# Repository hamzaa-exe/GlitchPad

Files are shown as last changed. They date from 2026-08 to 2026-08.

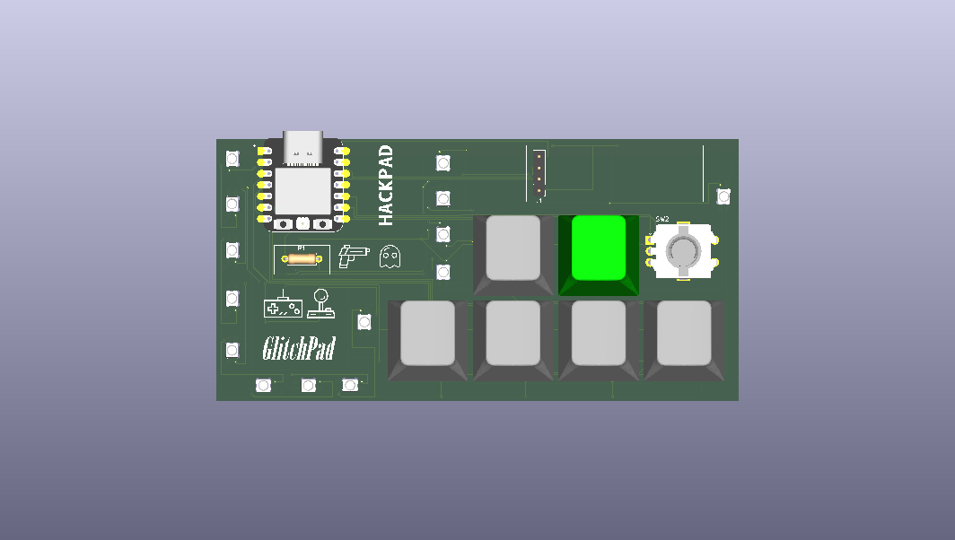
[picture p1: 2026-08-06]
PCB/GlitchPad.png

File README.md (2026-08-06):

# GlitchPad 

### A compact gaming macropad built for fast inputs, RGB glow, and cyberpunk vibes.

---

##  Renders

case final 1
GlitchPad
PCB FINALLLLLLLLL
schematic complete

##  What is GlitchPad?

**GlitchPad** is a custom gaming macropad built around the **Seeed XIAO RP2040**, **KMK firmware**, a rotary encoder, OLED display, and **20 SK6812 Mini-E RGB LEDs**.

It's designed mainly for FPS gaming, while still being fully customizable for other uses.

### Features

*  6 Cherry MX-compatible switches
*  EC11 rotary encoder
*  0.91" OLED display
*  20 × SK6812 Mini-E LEDs
*  XIAO RP2040
*  Custom 3D-printed case
*  Custom PCB
*  KMK firmware
*  Cyber-blue glitch lighting

---

##  Button Layout

```text
             SPACE       UP

             SHIFT      LEFT      DOWN      RIGHT
```

The rotary encoder is designed for quick number-based controls, such as switching between weapon slots in FPS games.

---

##  OLED + RGB

The OLED features a custom glitch-style animation, while the 20 SK6812 Mini-E LEDs provide a **cyber-blue pulse** aesthetic.

---

##  BOM

See the complete Bill of Materials here:

**[View BOM](./BOM.md)**

---

##  Tools

* **KiCad** — PCB & schematic
* **Fusion 360** — CAD & case
* **KMK + CircuitPython** — Firmware

---

##  Why GlitchPad?

I wanted to build a compact gaming controller while learning more about **PCB design, CAD, firmware, and hardware manufacturing**.

Six buttons. One encoder. Twenty LEDs.

**That's GlitchPad. **

---

##  Author

**Hamza Sohail**

Built for **Hack Club Hackpad**.

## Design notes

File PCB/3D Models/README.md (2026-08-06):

This folder include all 3D models used in PCB designimg

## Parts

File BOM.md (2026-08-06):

## Bill of Materials (BOM)

| **Component** | **Specification** | **Quantity** |
|---|---|---:|
| **Microcontroller** | Seeed XIAO RP2040 | 1 |
| **Mechanical switches**| Cherry MX-compatible switches | 6 |
| **Keycaps** | Cherry MX-compatible | 6 |
| **Rotary encoder** | EC11 rotary encoder | 1 |
| **OLED display** | 0.91" I²C OLED, 128×32 | 1 |
| **RGB LEDs** | SK6812 Mini-E | 20 |
| **Resistor** | 330 Ω | 1 |
| **PCB** | Custom GlitchPad PCB | 1 |
| **Case** | Custom 3D-printed case | 1 |
| **Screws** | M3 × 16 mm | 4 |
| **USB cable** | Compatible with XIAO RP2040 | 1 |

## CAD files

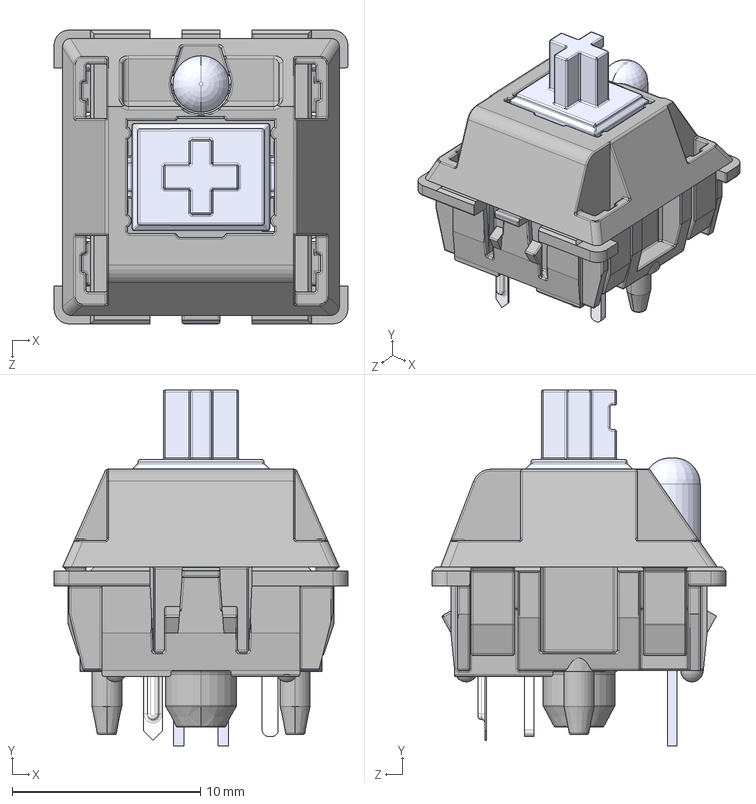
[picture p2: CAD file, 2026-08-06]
PCB/3D Models/MX .STEP
15.6 x 18.9 x 15.6 mm
MX 轴 按键′_ü___¨1
MX 轴 轴体áì_¨￠¨__
MX粣 拸簽LEDLEDLED
MX轴 轴体 底部 μ×2__默认_á2____è_
针脚___默认__è_

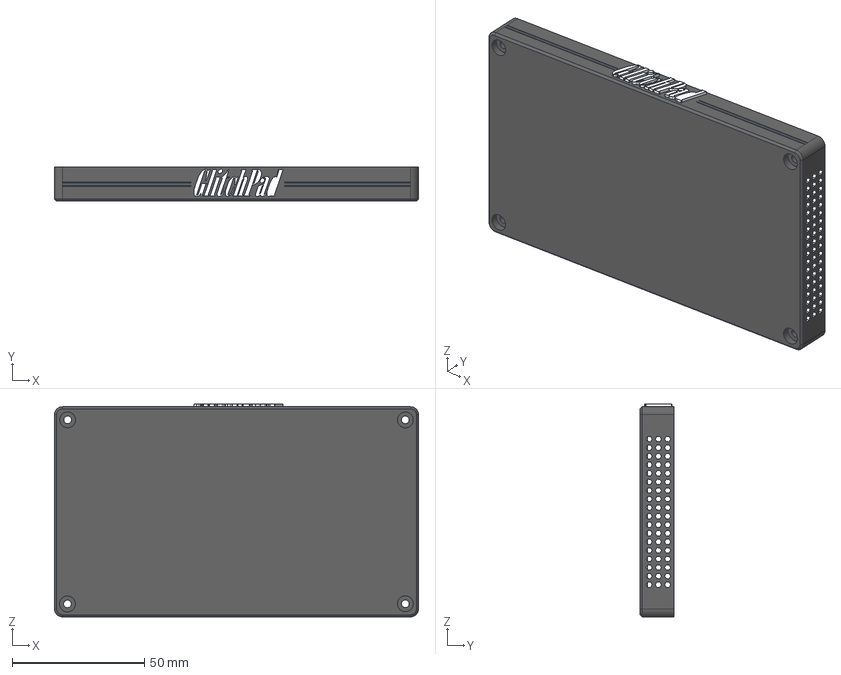
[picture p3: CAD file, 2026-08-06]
production/GlitchPad Case.step
137.5 x 13.0 x 80.4 mm

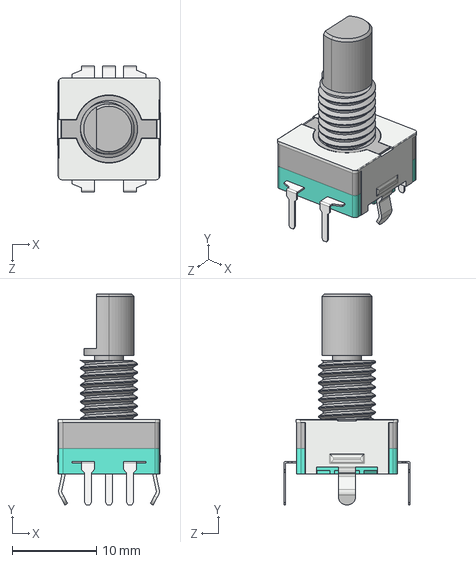
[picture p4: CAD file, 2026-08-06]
PCB/3D Models/旋转编码器.STEP
12.3 x 25.1 x 15.0 mm

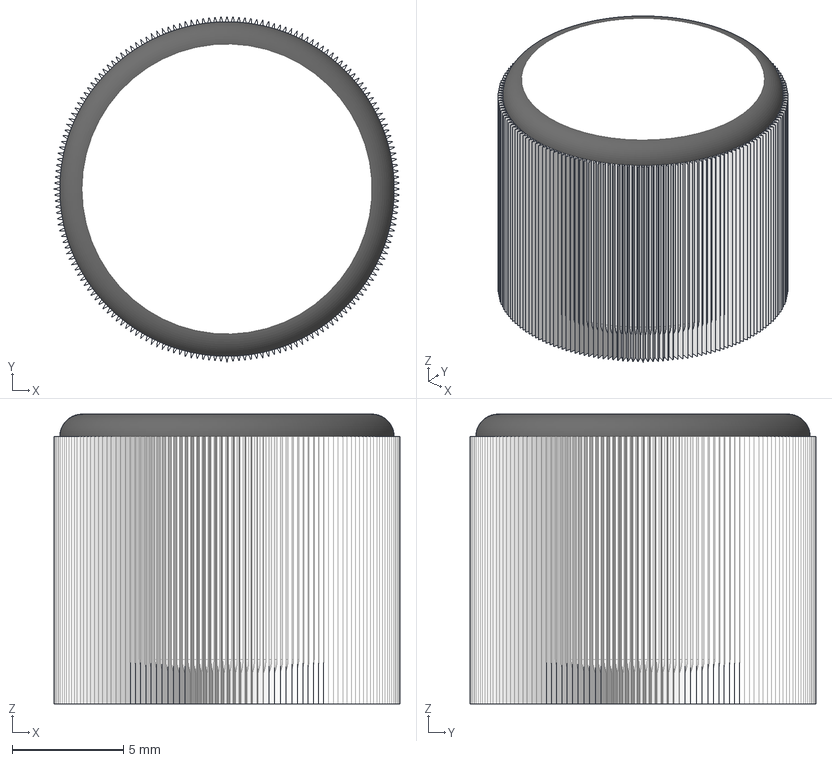
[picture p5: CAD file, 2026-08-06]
production/GlitchPad knob.step
15.5 x 15.5 x 13.0 mm

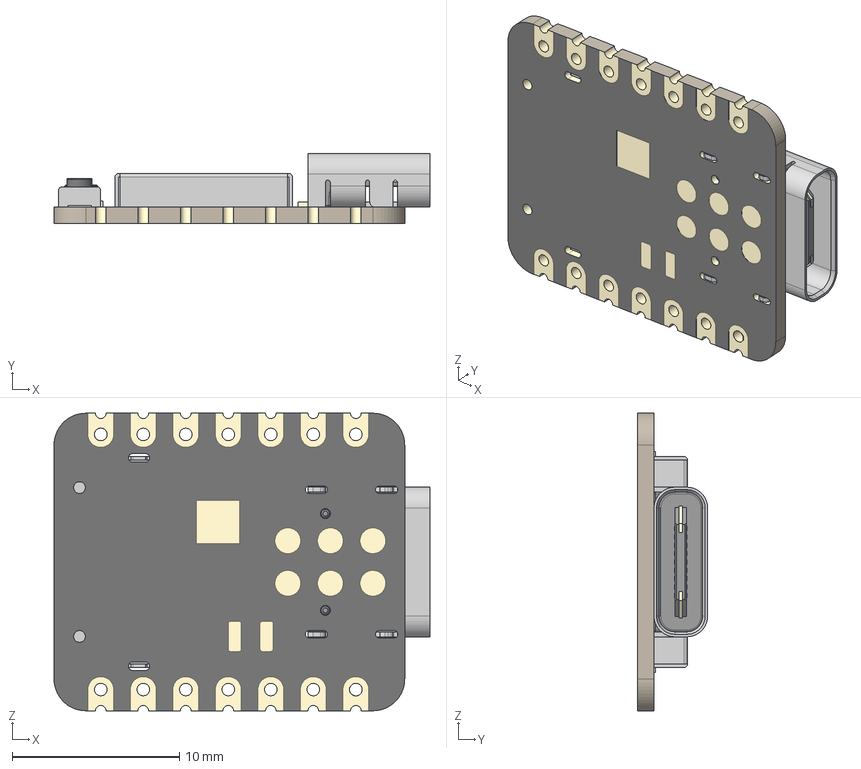
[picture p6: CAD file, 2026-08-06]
PCB/3D Models/Seeed Studio XIAO-ESP32-C3.step
22.5 x 4.21 x 17.8 mm
BOSS-EXTRUDE14_8_
BOSS-EXTRUDE7_4_
BOSS-EXTRUDE7_3_
BOSS-EXTRUDE14_4_
BOSS-EXTRUDE14_2_
BOSS-EXTRUDE14_11_
BOSS-EXTRUDE7_7_
BOSS-EXTRUDE14_9_
BOSS-EXTRUDE14_3_
BOSS-EXTRUDE14_7_
MIRROR2
BOSS-EXTRUDE14_5_
BOSS-EXTRUDE14_12_
BOSS-EXTRUDE7_8_
BOSS-EXTRUDE7_1_
BOSS-EXTRUDE14_10_
BOSS-EXTRUDE7_9_
BOSS-EXTRUDE14_6_
BOSS-EXTRUDE14_1_
BOSS-EXTRUDE7_6_
BOSS-EXTRUDE7_2_
CUT-EXTRUDE5
BOSS-EXTRUDE7_5_
U.FL Connector v1
Button (1) x 2
Shield

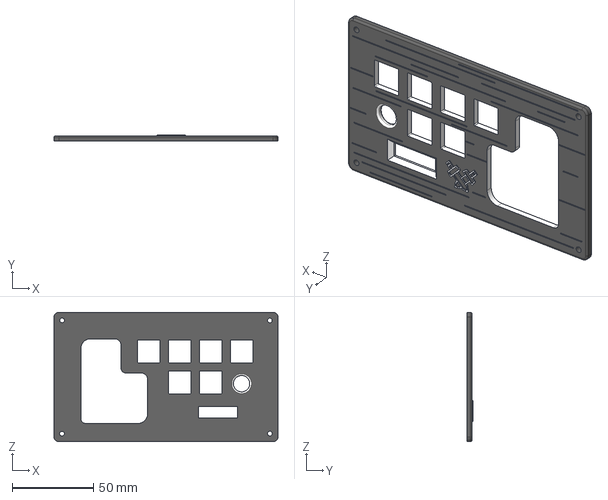
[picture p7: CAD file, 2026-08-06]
production/GlitchPad Case (Upper).step
137.5 x 3.50 x 79.4 mm

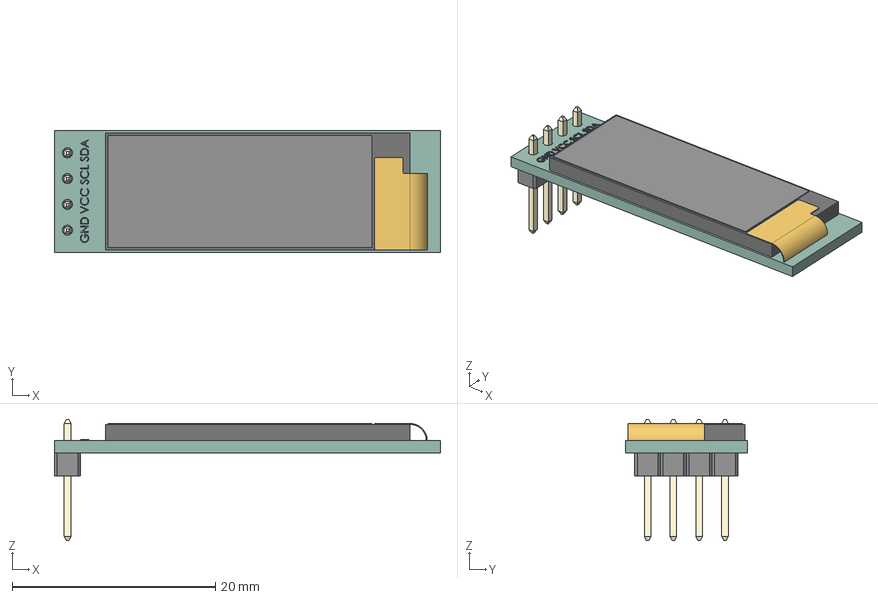
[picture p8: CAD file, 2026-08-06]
PCB/3D Models/128x32-OLED.STEP
38.0 x 12.0 x 11.9 mm

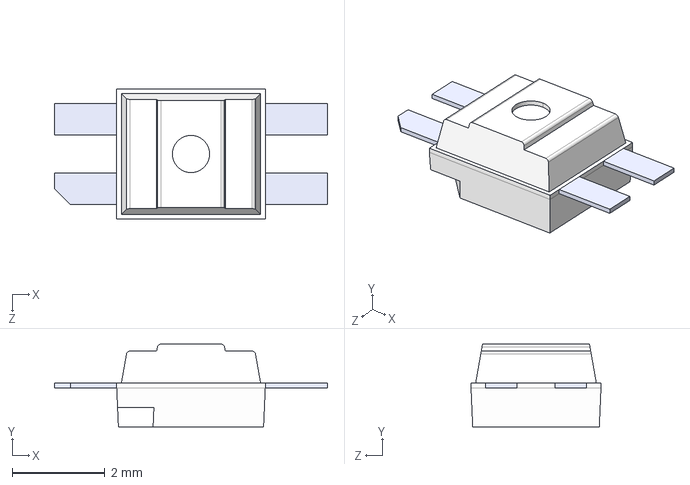
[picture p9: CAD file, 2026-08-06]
PCB/3D Models/SK6812MINI-E--3DModel-STEP-418109.STEP
5.88 x 1.78 x 2.80 mm

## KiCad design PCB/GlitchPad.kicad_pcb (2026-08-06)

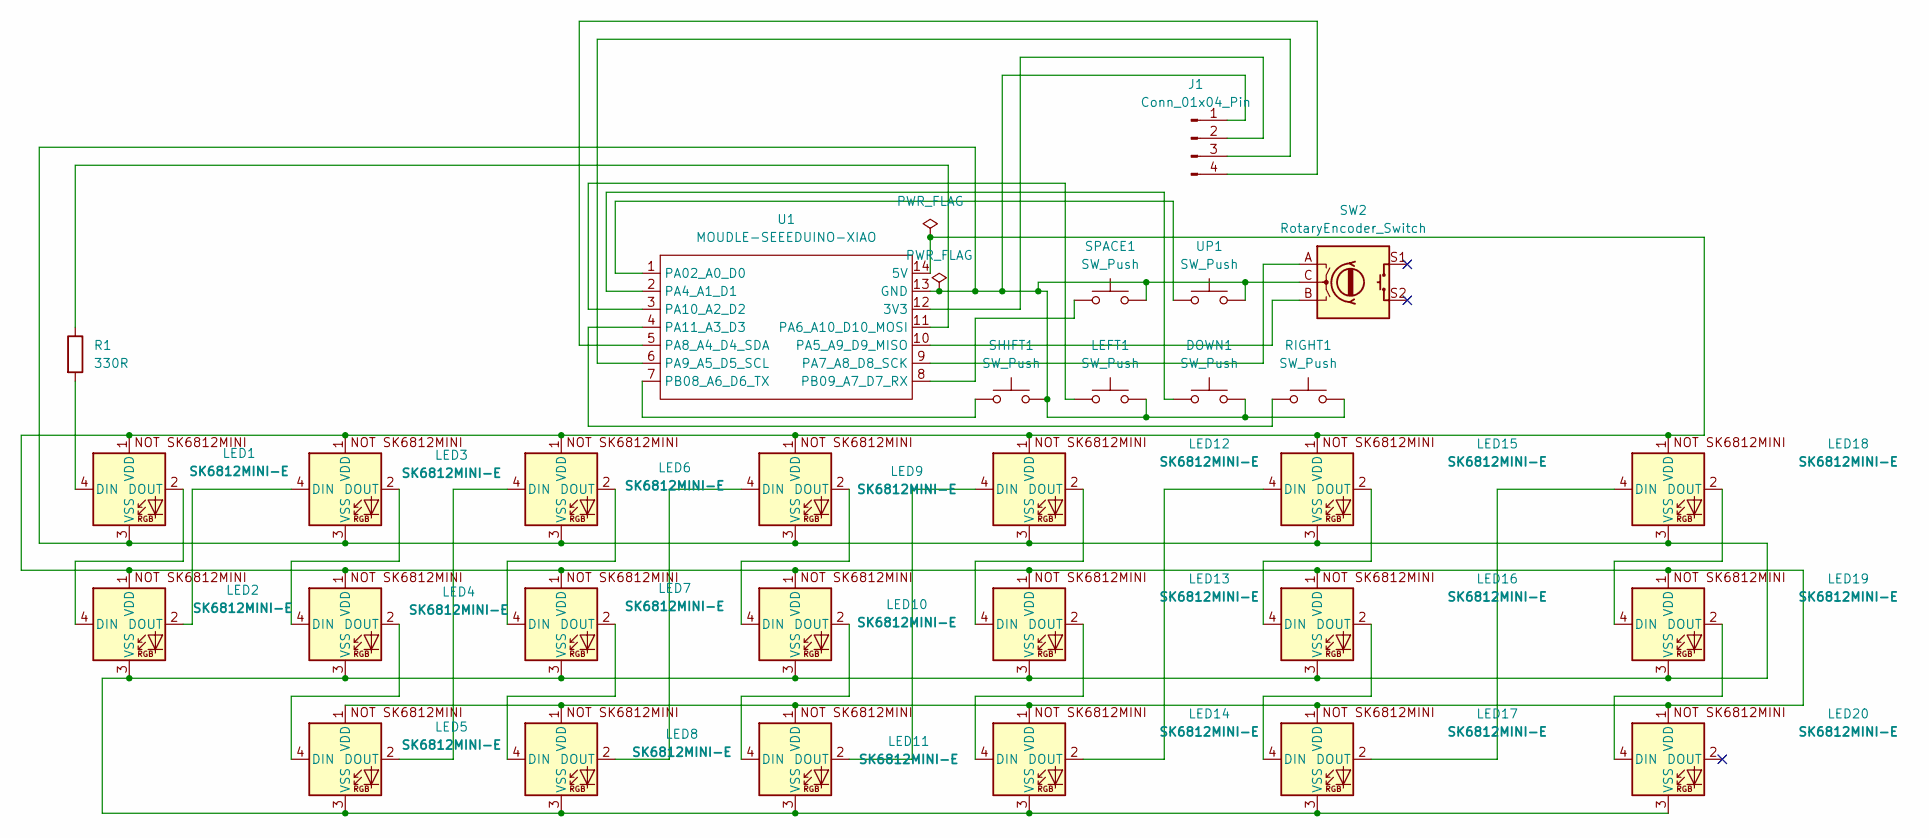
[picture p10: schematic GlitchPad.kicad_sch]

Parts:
DOWN1: SW_Push; SW_Cherry_MX_1.00u_PCB
J1: Conn_01x04_Pin; PinHeader_1x04_P2.54mm_Vertical
LED1, LED2, LED3, LED4, LED5, LED6, LED7, LED8, LED9, LED10, LED11, LED12, LED13, LED14, LED15, LED16, LED17, LED18, LED19, LED20: SK6812MINI-E; SK6812MINI-E_fixed
LEFT1: SW_Push; SW_Cherry_MX_1.00u_PCB
R1: 330R; R_Axial_DIN0207_L6.3mm_D2.5mm_P7.62mm_Horizontal
RIGHT1: SW_Push; SW_Cherry_MX_1.00u_PCB
SHIFT1: SW_Push; SW_Cherry_MX_1.00u_PCB
SPACE1: SW_Push; SW_Cherry_MX_1.00u_PCB
SW2: RotaryEncoder_Switch; RotaryEncoder_Alps_EC11E-Switch_Vertical_H20mm
U1: MOUDLE-SEEEDUINO-XIAO; XIAO-Generic-Hybrid-14P-2.54-21X17.8MM
UP1: SW_Push; SW_Cherry_MX_1.00u_PCB

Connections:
unnamed: DOWN1.2, J1.1, LED1.3 (VSS), LED2.3 (VSS), LED3.3 (VSS), LED4.3 (VSS), LED5.3 (VSS), LED6.3 (VSS), LED7.3 (VSS), LED8.3 (VSS), LED9.3 (VSS), LED10.3 (VSS), LED11.3 (VSS), LED12.3 (VSS), LED13.3 (VSS), LED14.3 (VSS), LED15.3 (VSS), LED16.3 (VSS), LED17.3 (VSS), LED18.3 (VSS), LED19.3 (VSS), LED20.3 (VSS), LEFT1.2, RIGHT1.2, SHIFT1.2, SPACE1.2, SW2.C, U1.13 (GND), UP1.2
unnamed: J1.2, U1.12 (3V3)
unnamed: J1.3, U1.6 (PA9_A5_D5_SCL)
unnamed: J1.4, U1.5 (PA8_A4_D4_SDA)
unnamed: LED1.4 (DIN), R1.2
unnamed: LED1.2 (DOUT), LED2.4 (DIN)
unnamed: LED1.1 (VDD), LED2.1 (VDD), LED3.1 (VDD), LED4.1 (VDD), LED5.1 (VDD), LED6.1 (VDD), LED7.1 (VDD), LED8.1 (VDD), LED9.1 (VDD), LED10.1 (VDD), LED11.1 (VDD), LED12.1 (VDD), LED13.1 (VDD), LED14.1 (VDD), LED15.1 (VDD), LED16.1 (VDD), LED17.1 (VDD), LED18.1 (VDD), LED19.1 (VDD), LED20.1 (VDD), U1.14 (5V)
unnamed: LED2.2 (DOUT), LED3.4 (DIN)
unnamed: LED3.2 (DOUT), LED4.4 (DIN)
unnamed: LED4.2 (DOUT), LED5.4 (DIN)
unnamed: LED5.2 (DOUT), LED6.4 (DIN)
unnamed: LED6.2 (DOUT), LED7.4 (DIN)
unnamed: LED7.2 (DOUT), LED8.4 (DIN)
unnamed: LED8.2 (DOUT), LED9.4 (DIN)
unnamed: LED9.2 (DOUT), LED10.4 (DIN)
unnamed: LED10.2 (DOUT), LED11.4 (DIN)
unnamed: LED11.2 (DOUT), LED12.4 (DIN)
unnamed: LED12.2 (DOUT), LED13.4 (DIN)
unnamed: LED13.2 (DOUT), LED14.4 (DIN)
unnamed: LED14.2 (DOUT), LED15.4 (DIN)
unnamed: LED15.2 (DOUT), LED16.4 (DIN)
unnamed: LED16.2 (DOUT), LED17.4 (DIN)
unnamed: LED17.2 (DOUT), LED18.4 (DIN)
unnamed: LED18.2 (DOUT), LED19.4 (DIN)
unnamed: LED19.2 (DOUT), LED20.4 (DIN)
unnamed: U1.1 (PA02_A0_D0), UP1.1
unnamed: DOWN1.1, U1.2 (PA4_A1_D1)
unnamed: SW2.B, U1.10 (PA5_A9_D9_MISO)
unnamed: R1.1, U1.11 (PA6_A10_D10_MOSI)
unnamed: SW2.A, U1.9 (PA7_A8_D8_SCK)
unnamed: LEFT1.1, U1.3 (PA10_A2_D2)
unnamed: RIGHT1.1, U1.4 (PA11_A3_D3)
unnamed: SHIFT1.1, U1.7 (PB08_A6_D6_TX)
unnamed: SPACE1.1, U1.8 (PB09_A7_D7_RX)

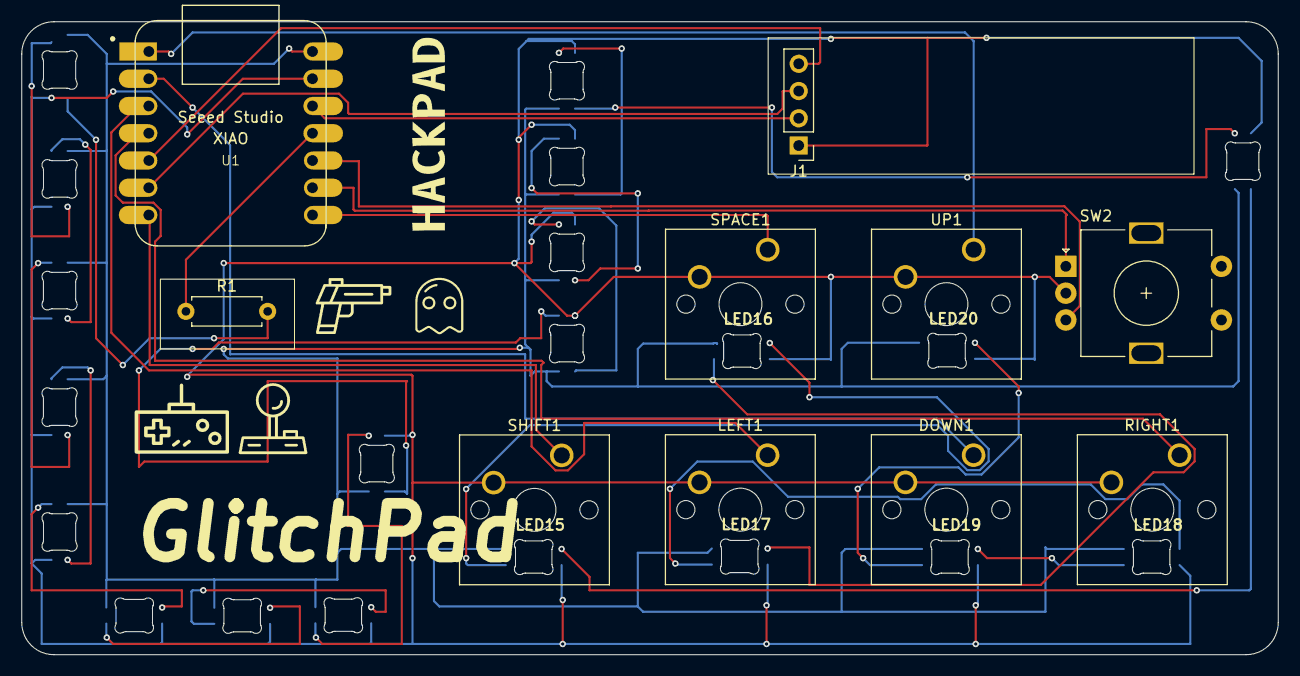
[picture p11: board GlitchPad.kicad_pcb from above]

Board: 2 copper layers, 117.1 x 59.0 mm, 30 parts (0 on the bottom side), 34 nets.

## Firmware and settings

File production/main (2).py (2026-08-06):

import time
import math
import board
import busio
import neopixel

from kmk.kmk_keyboard import KMKKeyboard
from kmk.keys import KC
from kmk.scanners.keypad import KeysScanner
from kmk.modules.encoder import EncoderHandler


# ============================================================
# GLITCHPAD
# ============================================================

keyboard = KMKKeyboard()


# ============================================================
# BUTTONS — DIRECT GPIO
#
# Each switch:
# GPIO ---- SWITCH ---- GND
#
# D0 = UP
# D1 = DOWN
# D2 = LEFT
# D3 = RIGHT
# D6 = SHIFT
# D7 = SPACE
# ============================================================

BUTTON_PINS = [
board.D0, # UP
board.D1, # DOWN
board.D2, # LEFT
board.D3, # RIGHT
board.D6, # SHIFT
board.D7, # SPACE
]

keyboard.matrix = KeysScanner(
pins=BUTTON_PINS,
value_when_pressed=False,
pull=True,
)

keyboard.keymap = [
[
KC.UP,
KC.DOWN,
KC.LEFT,
KC.RIGHT,
KC.LSFT,
KC.SPC,
]
]


# ============================================================
# ROTARY ENCODER
#
# D8 = A
# D9 = B
# C = GND
#
# Rotation selects number slots 1-9.
# ============================================================

encoder_handler = EncoderHandler()

encoder_handler.pins = (
(board.D8, board.D9, None, True),
)

encoder_handler.map = [
(
(KC.N1, KC.N2),
),
]

keyboard.modules.append(encoder_handler)


# ============================================================
# OLED
#
# D4 = SDA
# D5 = SCL
#
# 128 x 32 I2C OLED
# ============================================================

import adafruit_ssd1306

i2c = busio.I2C(
board.D5,
board.D4,
)

oled = adafruit_ssd1306.SSD1306_I2C(
128,
32,
i2c,
addr=0x3C,
)


# ============================================================
# SK6812 MINI-E
#
# D10 = LED1 DIN
# 20 LEDs total
# ============================================================

LED_COUNT = 20

pixels = neopixel.NeoPixel(
board.D10,
LED_COUNT,
brightness=0.15,
auto_write=False,
)


# ============================================================
# RGB — CYBER BLUE PULSE
# ============================================================

def update_rgb():
t = time.monotonic()

pulse = int(
20 + (math.sin(t * 4) + 1) * 25
)

for i in range(LED_COUNT):
variation = (i * 3) % 12

pixels[i] = (
0,
min(80, pulse // 3 + variation),
min(120, pulse + variation),
)

pixels.show()


# ============================================================
# OLED GLITCH DISPLAY
# ============================================================

glitch_text = [
"GLITCHPAD",
"GL1TCHPAD",
"GL!TCHPAD",
"GLITCHP4D",
]

frame = 0
last_oled_update = 0


def update_oled():
global frame
global last_oled_update

now = time.monotonic()

if now - last_oled_update < 0.18:
return

last_oled_update = now

oled.fill(0)

# Title
oled.text(
glitch_text[frame],
10,
0,
1,
)

# Status
oled.text(
"SYSTEM ONLINE",
5,
12,
1,
)

# Animated glitch bar
bar_length = (frame * 18) % 120

oled.fill_rect(
4,
23,
bar_length,
2,
1,
)

oled.text(
"READY",
48,
26,
1,
)

oled.show()

frame = (frame + 1) % len(glitch_text)


# ============================================================
# STARTUP
# ============================================================

oled.fill(0)
oled.text("GLITCHPAD", 25, 5, 1)
oled.text("BOOTING...", 25, 20, 1)
oled.show()

pixels.fill((0, 10, 30))
pixels.show()

time.sleep(1)

oled.fill(0)
oled.show()


# ============================================================
# KMK START
# ============================================================

if __name__ == "__main__":
keyboard.go()

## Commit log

2026-08-05 Create PCB
2026-08-05 Create CAD
2026-08-06 3D models in PCB folder
2026-08-06 Create BOM
2026-11-11 Sync PCBs from Half Life
